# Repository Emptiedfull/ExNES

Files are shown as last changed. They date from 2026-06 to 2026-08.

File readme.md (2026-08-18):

# EXNES

A cycle accurate emulator for the Nintendo Entertainment System written in go, built for performance and compatiblity

The core offers a standalone package without any external dependencies and no timing, rendering or audio management preferences. Allowing for extensive compatiblity and ease of use. 

This repo ships with a sdl frontend for native applications and a web build that runs straight in the browser using web assembly. 

## Playing it 

### Web 

<p align="center">
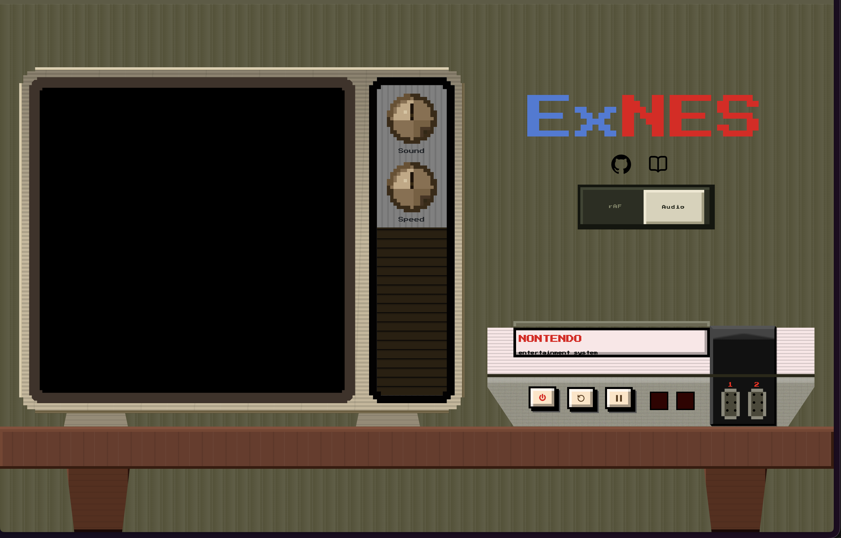
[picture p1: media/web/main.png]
  
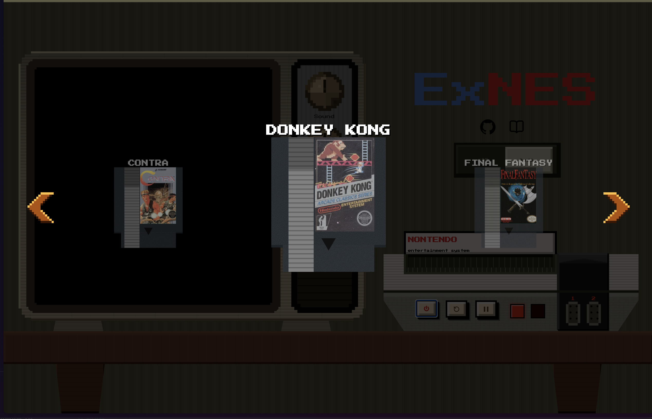
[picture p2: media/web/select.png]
   
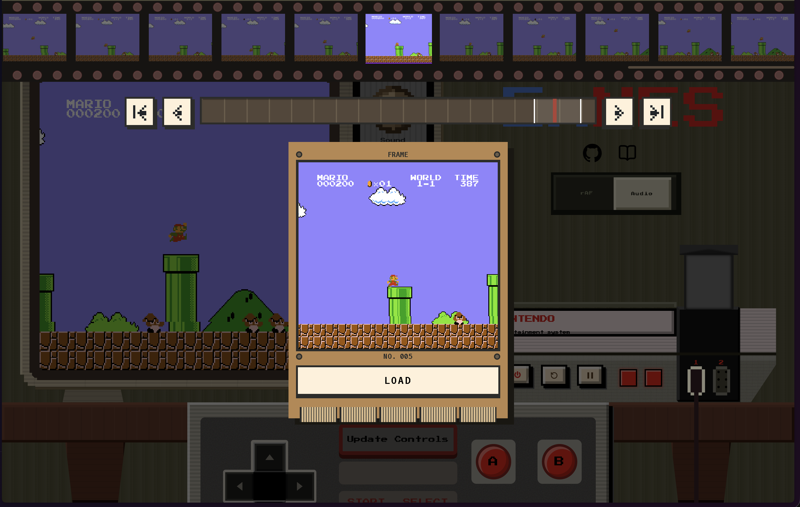
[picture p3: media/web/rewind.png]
    
</p>

The web build runs in any browser with support for shared memory array buffers (most major modern browsers). It is currently only playable on desktop browsers however. A curated set of roms is available built in however support for custom roms is not present. 

> **Hosted at:** https://exnes.a.shipwrights.dev/

## Native builds

<p align="center">
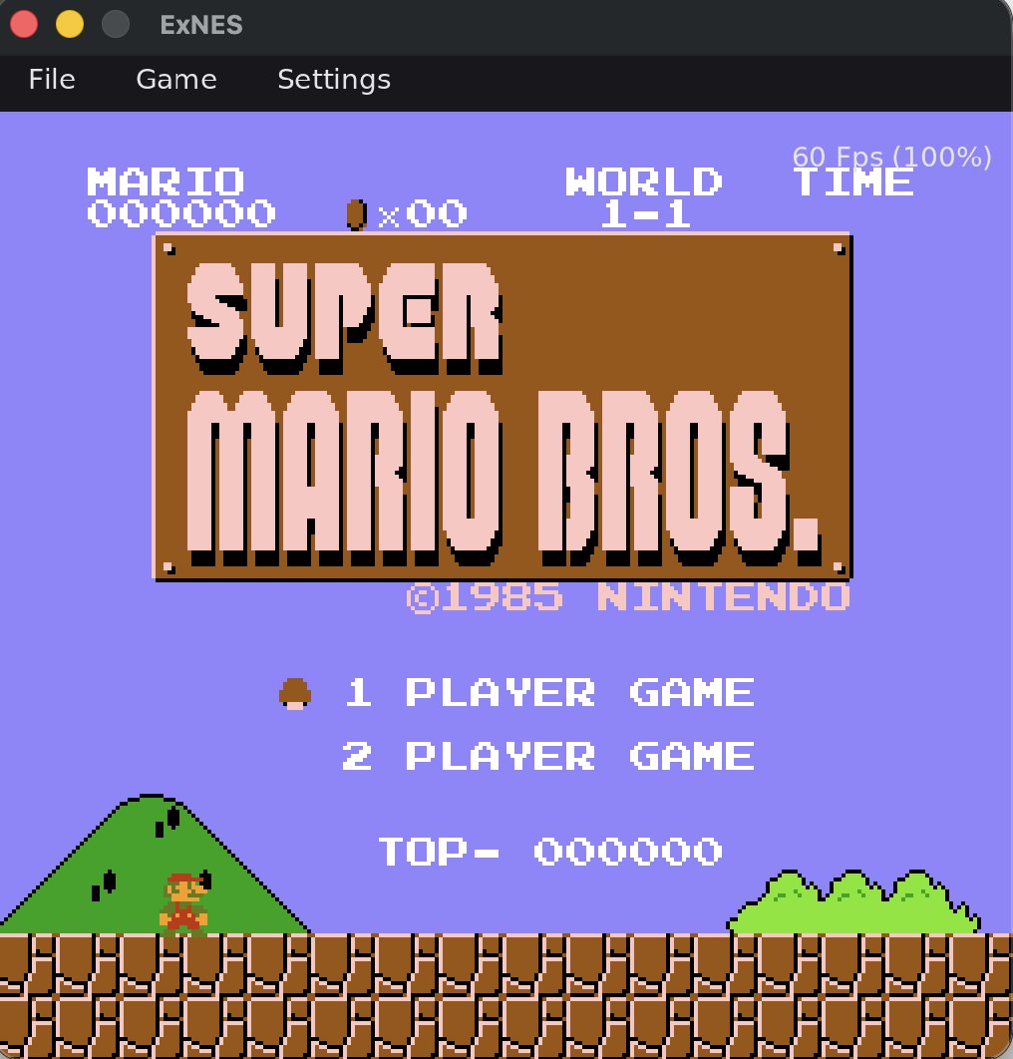
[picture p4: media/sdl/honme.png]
  
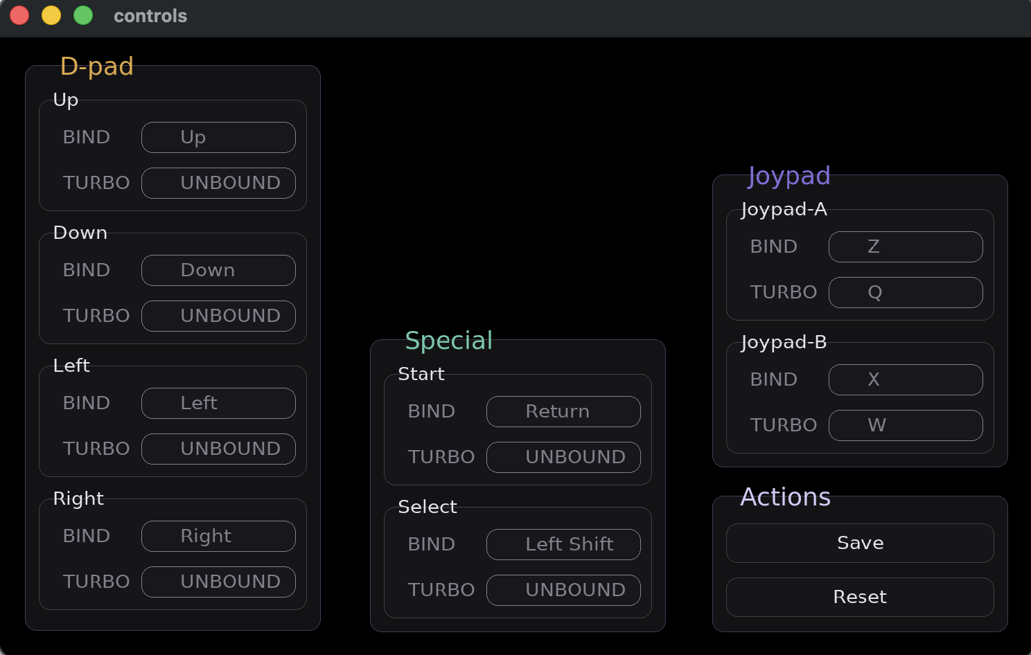
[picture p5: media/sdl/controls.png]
   
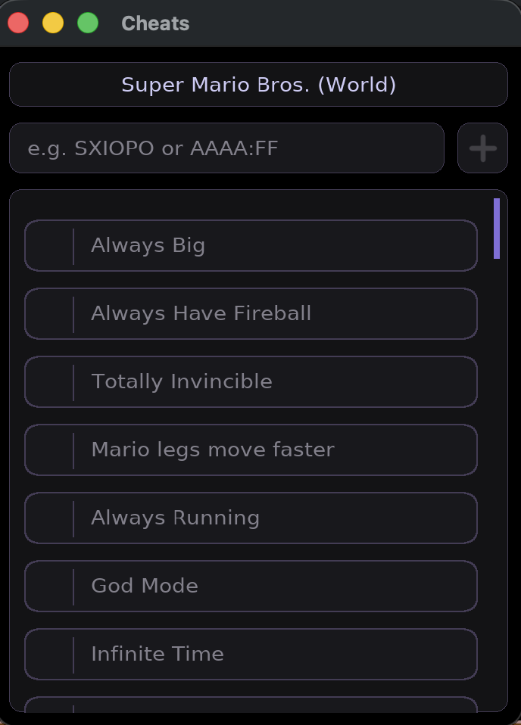
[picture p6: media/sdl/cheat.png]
    
</p>

Executables for Windows, Mac and Linux are available on the releases page. 

### Linux 

Release for linux happens through AppImages, there are no prerequisite dependencies or package manager involved. Stable AppImages can found in the releases page.

```
chmod +x ExNES-x86_64.AppImage
./ExNES-x86_64.AppImage
```
The appImage was built against `Debian 12(glic 2.36)` and hence will not work on older legacy systems, these including distributions like Ubuntu 22.04 and RHEL 8. On these systems build from source instead, a list of needed dependencies can be found in ` AppImage.sh `

### Mac 

MacOS version ships as a `.dmg` for both silicon based and intel based Macs. Due to the unsigned nature of the binary (it costs an arm and leg), the first run will require to explicity allow execution by going to `Settings > Privacy`.

> Dragging and Dropping files on the macOS edition will cause the emulator to crash, this is a known issue with no fix currently.

### Windows

Every release ships two options.

**Portable zip.** Download `ExNES-windows-x86_64.zip`, unpack it anywhere, and run
`exnes.exe`. Nothing is installed and nothing is written outside the app's own
config directory.

**Installer.** Download `ExNES-<version>-windows-x64-setup.exe` and run it. It
installs per-user by default, so Windows never prompts for admin rights, and it
adds Start Menu and optional desktop shortcuts.

Both are self-contained, SDL2 and everything else is bundled alongside the exe,
so there is no runtime to install and no package manager involved. 

The installer additionally registers `.nes` as a file type, which lets you launch
a ROM by double-clicking it, via right-click → Open With, or by dropping it onto
the ExNES icon.

> Neither download is code-signed yet, so SmartScreen will show a
> "Windows protected your PC" warning on first run. Click **More info** →
> **Run anyway**.
### Controls 

The default mappings are common across the native builds and are as follows: 

| NES button | Key | Turbo |
|---|---|---|
| D-pad | Arrow keys | — |
| A | `Z` | `Q` |
| B | `X` | `W` |
| Start | `Enter` | — |
| Select | `Left Shift` | — |

The default mappings can be changed by going to `Settings > Input`

Turbo buttons act like turbo buttons on the pro nes controllers and spam a given input while they are held.

### Whats included 

The desktop build comes with a sdl based application window with a lightweight custom made graphics and state handler. 

- Loading rom files from memory with recent files support 
- 10 Save states linked to ROM's hash 
- Battery backed ram support for included Mappers 
- Support for emulation control: Pause,Unpause,Reset,Power Cycle,etc
- Cheat suport in both memory and code format
- Hash based database support linked to cheats menu 
- Support for variable emualtion speed upto 3x
- Volume and fps control 
- Support for dynamic pallete changes
- Customizable controls 
- Turbo controls 
- File associations for os-dependent context menus 

All settings and battery backed ram saves are persistent and stored in: 

| Platform | Path |
|---|---|
| Linux | `~/.config/exnes` |
| macOS | `~/Library/Application Support/exnes` |
| Windows | `%AppData%\exnes` |

## Running it locally 

### Building from Source

Requires Go 1.24+, cgo, and SDL2 development headers.

> Installing depts:

```sh
# Debian / Ubuntu
sudo apt install libsdl2-dev libsdl2-ttf-dev libsdl2-image-dev libsdl2-gfx-dev
 
# macOS
brew install sdl2 sdl2_ttf sdl2_image sdl2_gfx
 
# MSYS2 (MINGW64 shell)
pacman -S mingw-w64-x86_64-toolchain mingw-w64-x86_64-SDL2 \
          mingw-w64-x86_64-SDL2_ttf mingw-w64-x86_64-SDL2_image \
          mingw-w64-x86_64-SDL2_gfx
```

> Building Binary 

```sh
go build -o exnes ./cmd/sdl
./exnes
```

### Using Release artifacts 

`.github/workflows/build.yml` builds all 4 dispatches on every github release, or on a manual action. 

For producing them locally: 

| Target | Command | Output |
|---|---|---|
| Linux  | `docker build -t exnes-build build/` then `build/AppImage.sh` | `dist/*.AppImage` |
| macOS `.dmg` | `bash build/macos.sh` | `dist/*.dmg` |
| Windows `.zip` | `bash build/windows.sh` (MSYS2 MINGW64) | `dist/*.zip` |
| Windows installer | `iscc /DAppVersion=1.0.0 build\installer.iss` | `dist/*-setup.exe` | 

### Running web build 

**Production:** The repository root has a `dockerfile` and `Caddyfile` that work as-is anywhere Docker runs:

```sh 
docker build -t exnes-web 
docker run -p 6000:80 exnes-web
```

The port can be manually changed in the `Caddyfile` but it currently lacks env variable support.

**Development:** `cmd/wasm/server` is a custom built development server specifically made for this project, by default it comes with automatic Wasm recompilation and bundling, brotli compression backed by an in memory cache, and generation support for files used by frontend. 

The default port is set to 8070

```sh
go run ./cmd/wasm/server
```

### Features

| Feature | Native build | Web build |
|---|---| --- |
| Speed Adjustment | ✅ |  ✅ | 
| Audio | ✅ |  ✅ | 
| Cheats | ✅ |  ❌ | 
| RAM memory |  ✅ | | 
| Rom Support | Custom |  Included | 

## Repository Map 

```
Core\           # Contains NES Core package 
Cmd\            # Entrypoints
    Sdl\            # Native frontend wtih sdl2
    Wasm\           # Web assembly build + Dev Server and bundler
    ssts\           # Test harness for single step tests
Build\          # Build scripts and artifacts
Media\          # Image gallery for readme
```

## Technical details 

### Emulator Core 

Present in ./CORE it contains all the neccesary functions and helpers responsible for emulating the NES Console.

It includes a cycle accurate 6502 Rioch 2A03 cpu with full opcode coverage including all illegal and unstable opcodes. These are tested against [SingleStepTests](https://github.com/SingleStepTests/65x02) `nes6502/v1`. Along with cycle accuracy for opcodes, it also contains cycle accurate state machines for interrupts.

NOTE: The cooked branch includes a sub cycle accurate RDY pin behaviour but it is currently unstable and cant be used freely without risk of crash. 

It also includes a dot accurate PPU working based on the og nes fetcher model stimulating all dummy reads and writes present in the dot, this is in conjuction with a dynamically swappable pallete engine with supports both single and full palettes.

The Apu is a standard 5 channel audio engine based on the global clock. 

The core has been built to maximize the accuracy while refraining from entering subcycle (or more) accurate behaviour to mitigate performance issues. This means it accurately stimulates a large amount of quirks and edge cases present in the orignal console. As per the latest release the emulator core scores 86 in the AccuracyCoin which puts it ahead of many commercial and nintendo made emulators for the NES.

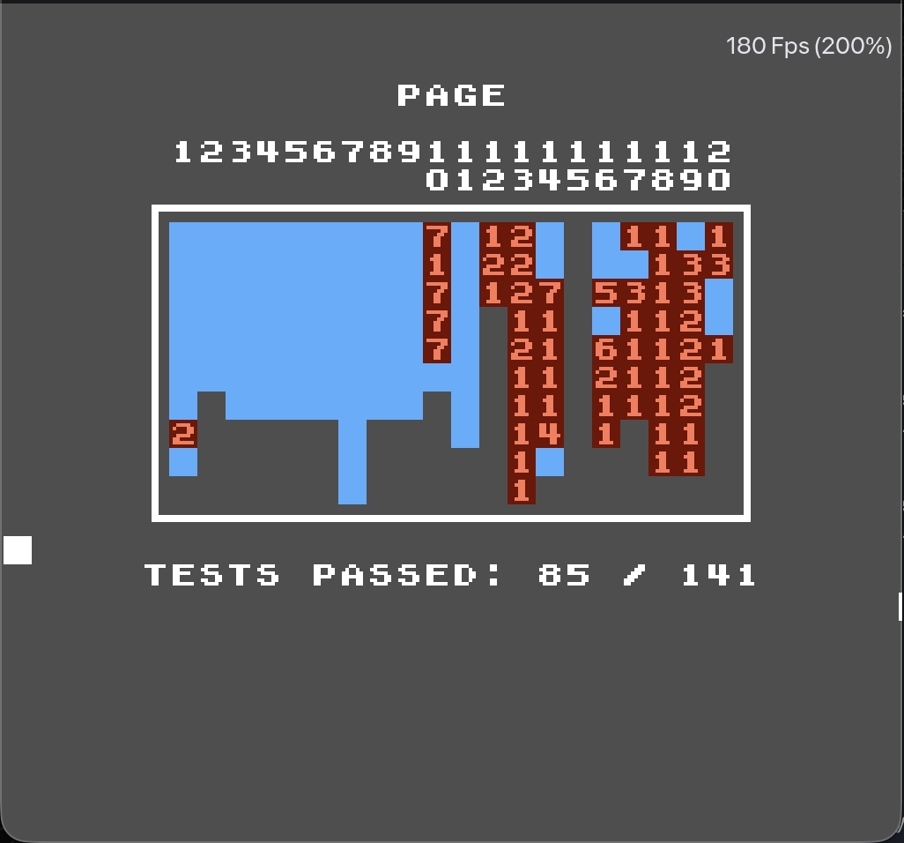
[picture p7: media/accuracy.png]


One thing to note is that the Core does not expose any timing mechanism on its own nor does it enforce any, consumption of the core needs to come with its own timing mechanism, it is recommend to either sync using runFrame at around 60fps or use the audio sample starvation for frame perfect emulation.

The core also included a cheat engine which supports game genie codes along with support for raw memory patches in the format of addr:val.

Also bundled in is a headerless No-Intro dataset for indentification of games, this information is used for generating accurate saves and it also connects with the cheat engine to provide all known cheats for a game through a easily querable function.

The documentation for how to use the core is scarce and not very intuituive, hence the best way to utilize it right now is looking at cmd/wasm and cmd/sdl for sample code. 

### Web build 

The web build serves the emulator core using web assembly, due to the single threaded nature of javascript runtime in browsers multiple threads with atomic messages run in parralel. 

These are the following:

1) Go web worker: Residing in emuWorker.js this thread owns the go runtime and runs the emulator itself, it spends most of time blocking on frame signals and can only be communicated using shared Array buffers.

2) Audio worklet: runs the audio worklet process, it is also responsible for driving the emulator thread when in audio synced mode. 

3) Main thread: It handles all the other processes including handling button inputs, cross thread communication and animations.

### Native build

The native build runs cross platform by utilizing the sdl library, it includes no dependencies apart from sdl including a layout engine. This means that every window contains its own discrete layout engine and state manager, a lot of this values are hardcoded for ease of development and thus extensions should be carefully made.

It is technically supposed to work on every platform due to the cross platform nature of golang and sdl, but its only been tested on macOs. Please report any issues on other platforms.

## Contributions 

Issues and pull requests are welcome. Platform reports are especially useful, the desktop build is tested mainly on macOS, so Linux and Windows regressions tend to be found by users rather than by CI.

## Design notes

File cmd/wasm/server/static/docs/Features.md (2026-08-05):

# Features

This page is a comphrensive list of all available features (hopefully)

## Console Controls 

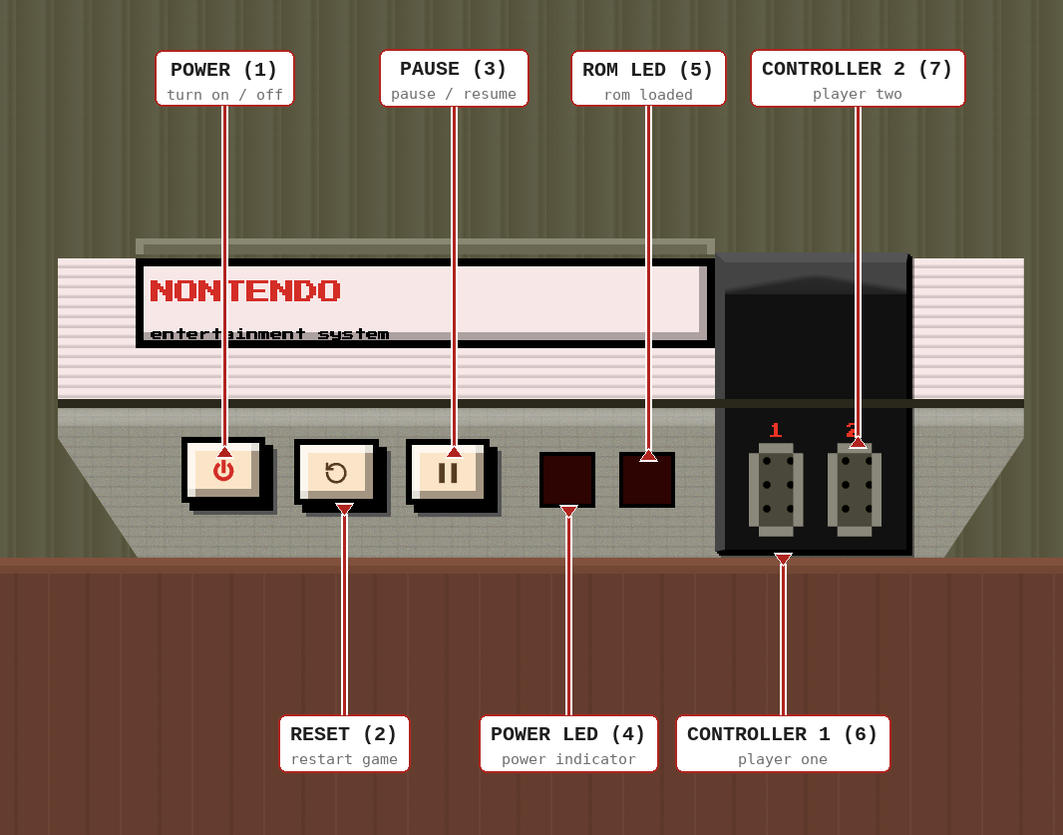
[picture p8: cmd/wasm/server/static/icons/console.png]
hehe


### Power button (1)

Controls the physical state of being **powered**. It also is the start of the console. Turning it on and off stimulates a **power cycle** like on the orignal NES.

## Reset (2)

Works like the **reset** button on the physical NES. May cause data corruption in some games (this is not a glitch, this is a artifact of accurate emulation)

## Play/Pause (3)

Can be used to control the state of emulation. The pausing action is not instant and may cause **5-10 frames** of lag.

### Power led and ROM Led (4 and 5)

This represent the state of the console at a given point. Note any flickering effects are purely **cosmetic** and do not affect 
usage.

If your rom has been loaded but the power led remains blank, use the **power button** to turn on the console.

### Controller ports (6 and 7)

Uh my bad they aren't really implemented yet but they would allow you to use external control devices and connect and disconnect input sources. Have a happy cat on me instead. 

### Catridge slot (8)

Press on the **slot** to open up the rom selection menu. Using it mid game can be used to hotswap games which can be used for some exploits in particular games, it can also however cause data corruption. Restart the tab to fix this.

***

## Television controls 

### Speed dial(1)

It can be used to control the **emulation speed** to slow or speed it up, by defualt the increment are in orders of **50%**. Only works in audio clocked mode.

### Volume dial(2)

Pretty obvious, controls the **audio volume**. Can be used to **mute** the program. Only works in audio clocking mode.

### Tv Screen

Clicking on the screen changes the display mode to **fullscreen**, the scaling is based on the browser auto scaling so pixel ratio might be distorted.

***

## Miscellanous 

### Timing control

Probably the most drastic control option you have the liberty to change. Check out [here](./docs/Timing.md) for more info

### Updating controls 

The **on screen controller** can be used to change up the controls, simply press the button and then rebind it with any keyboard key (or hopefully external controller but no promises). The onscreen controller can also be used to actually control the emulator btw!

### Rewind

You found the **easter egg**!!!! Press the R key on the keyboard to open up the **rewind** overlay, you can then use the timeline to scrub into a past frame from a collection of the **last 4 seconds of frames**. The frame can then be loaded into for rewinding, enjoy cheating you lil bitch.

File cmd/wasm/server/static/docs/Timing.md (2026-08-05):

# Timing Modes

ExNES supports a two different ways of timing the emulator clock. This should not concern most people but it can be the source of your problem. 

## Which mode to use? 

The default mode at start up is Audio clocked, this is because it has the most extensive feature support. However you might find that using audio clocked makes the game jittery try to switch to rAF Clocked.

## How to switch modes? 

Gng, its the most akward button on the screen, just use the slider beneath the hero text.

## Comparison 

| | Audio Clocked | rAF Clocked |
|---|---|---|
| Compatiblity | Medium | High |
| Frame rate | Frame perfect |  ~60 fps |
|Audio | Supported | Not Supported |

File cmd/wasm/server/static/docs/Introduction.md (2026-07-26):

# EXNES

Welcome to **ExNES**, a Nintendo Entertainment System emulator running using WASM. Use this page for getting started.

## Starting

The console starts off. To boot it up:

1. Press the **power button** (the ⏻ button on the console deck). 
2. Use the **navigation arrows**
  to browse through the available games.
3. Click the **selected cartridge** to slot it in.

## Controls

ExNES maps the NES controller to your keyboard by default. 

| Button | Keyboard Key |
| --- | --- |
| A | `Z` |
| B | `X` |
| Select | `Left Shift` |
| Start | `Enter` |
|  Up | `Arrow Up` |
|  Down | `Arrow Down` |
| Left | `Arrow Left` |
| Right. | `Arrow Right`|

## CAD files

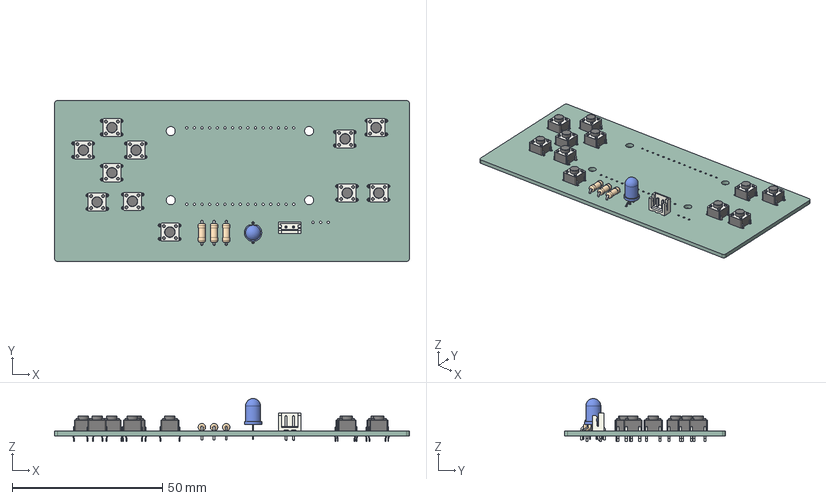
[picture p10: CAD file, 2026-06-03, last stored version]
controller_kicad/.step
118.0 x 53.5 x 14.3 mm
SW_PUSH_6mm_h5mm x 11
R_Axial_DIN0207_L63mm_D25mm_P762mm_Horizontal x 3
JST_B2B_EH_A
LED_D5.0mm-4_RGB_Wide_Pins
KiCad_PCB

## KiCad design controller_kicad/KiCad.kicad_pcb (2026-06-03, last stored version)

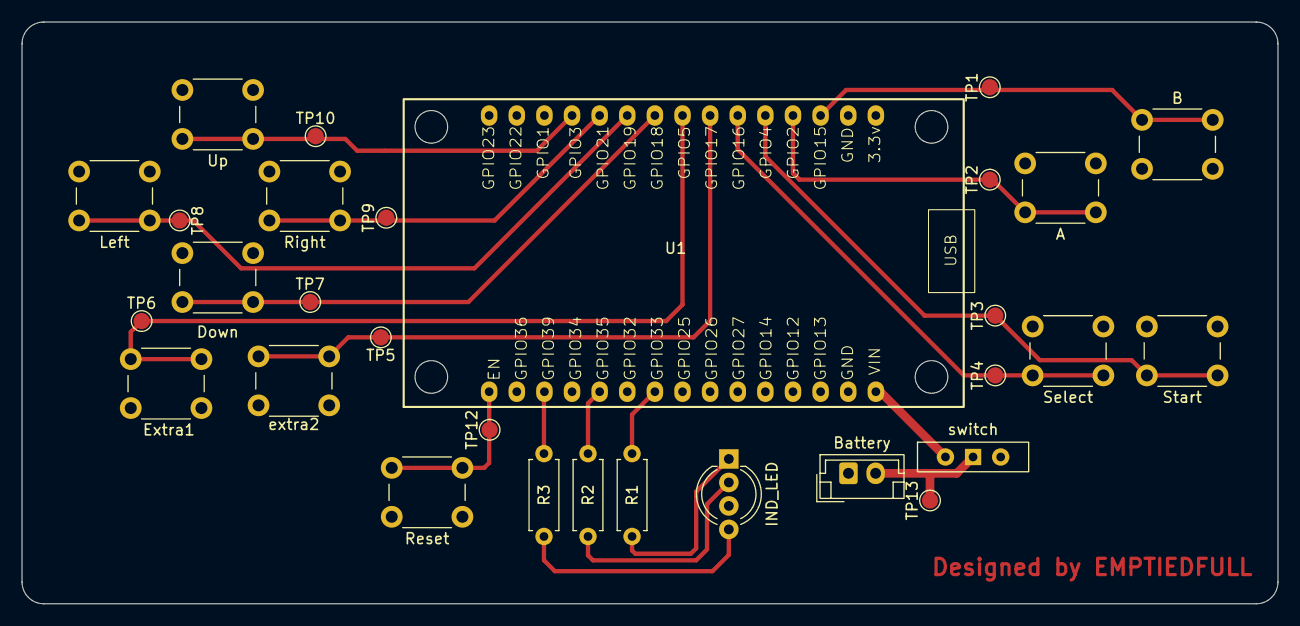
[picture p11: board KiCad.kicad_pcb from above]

Board: 2 copper layers, 115.5 x 53.5 mm, 30 parts (0 on the bottom side), 20 nets.

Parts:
A: ButtonA; SW_PUSH_6mm_H5mm
B: ButtonB; SW_PUSH_6mm_H5mm
Battery: GRND; JST_EH_B2B-EH-A_1x02_P2.50mm_Vertical
Down: ButtonStart; SW_PUSH_6mm_H5mm
Extra1: Extra1; SW_PUSH_6mm_H5mm
IND_LED: LED_BGKR; LED_D5.0mm-4_RGB_Wide_Pins
Left: ButtonSelect; SW_PUSH_6mm_H5mm
R1, R2, R3: R; R_Axial_DIN0207_L6.3mm_D2.5mm_P7.62mm_Horizontal
Reset: Reset; SW_PUSH_6mm_H5mm
Right: Extra1; SW_PUSH_6mm_H5mm
Select: ButtonSelect; SW_PUSH_6mm_H5mm
Start: ButtonStart; SW_PUSH_6mm_H5mm
TP1, TP2, TP3, TP4, TP5, TP6, TP7, TP8, TP9, TP10, TP12, TP13: TestPoint; TestPoint_Pad_D1.5mm
U1: ESP32_30pin
Up: Extra2; SW_PUSH_6mm_H5mm
extra2: Extra2; SW_PUSH_6mm_H5mm
switch: SW_SPDT; SW_Slide-03_Wuerth-WS-SLTV_10x2.5x6.4_P2.54mm

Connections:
unnamed: A.2, B.2, Battery.1, Down.2, Extra1.2, IND_LED.3 (K), Left.2, Reset.1, Right.2, Select.2, Start.2, U1.2 (GND), Up.2, extra2.2
unnamed: Battery.2, TP13.1 (1_1), switch.1 (A)
unnamed: IND_LED.1 (BA), R1.2
unnamed: IND_LED.2 (GA), R2.2
unnamed: IND_LED.4 (RA), R3.2
unnamed: U1.1 (VIN), switch.2 (B)
unnamed: Reset.2, TP12.1 (1_1), U1.15 (EN)
unnamed: A.1, TP2.1 (1_1), U1.19 (GPIO2)
unnamed: TP10.1 (1_1), U1.27 (GPIO3), Up.1
unnamed: Start.1, TP3.1 (1_1), U1.20 (GPIO4)
unnamed: Extra1.1, TP6.1 (1_1), U1.23 (GPIO5)
unnamed: B.1, TP1.1 (1_1), U1.18 (GPIO15)
unnamed: Select.1, TP4.1 (1_1), U1.21 (GPIO16)
unnamed: TP5.1 (1_1), U1.22 (GPIO17), extra2.1
unnamed: Down.1, TP7.1 (1_1), U1.24 (GPIO18)
unnamed: Left.1, TP8.1 (1_1), U1.25 (GPIO19)
unnamed: Right.1, TP9.1 (1_1), U1.26 (GPIO21)
unnamed: R1.1, U1.9 (GPIO33)
unnamed: R2.1, U1.11 (GPIO35)
unnamed: R3.1, U1.13 (GPIO39)

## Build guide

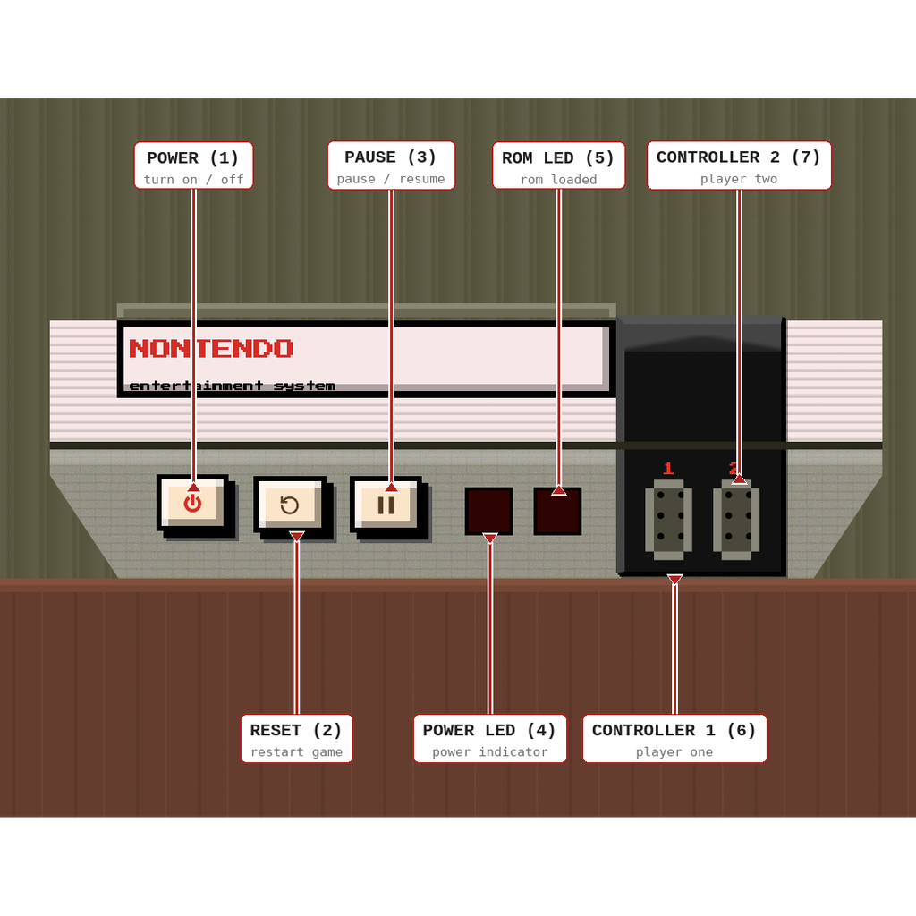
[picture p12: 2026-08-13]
build/exnes-1024.png

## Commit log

2026-06-03 controller-pcb added
    [.step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]
2026-06-03 Update README with PCB design and images
    Added images and updated PCB design information in README.
2026-06-03 added bom
    [bom.csv]
2026-06-04 socket support
2026-06-05 control n socket barely working
2026-06-11 better frame handling(like way better went from +- 10000 variation to +-2 variation of cycles
2026-06-12 switching to dot based rendering
2026-06-12 ppu switch complete-bugs remaining
2026-06-14 project restructing n pruning extra files
    [.step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]
2026-06-14 switched to tinygo compilation
2026-06-16 rom slottin
2026-06-18 apu prototype done
2026-06-19 complete audio driven+switched from oto to malgo
2026-06-20 switched to aduoi worklet
2026-06-21 switched to web worker for wasm
2026-06-26 added modal links with animations + added pause play and rom hotswap support is back(still gotta add buttons but yeh
2026-06-28 switched to a new icon library and added key animations for them
2026-06-29 changed pallete access to be branchless and hooked up pause button, also removed some logging calls
2026-07-01 new styles and animations for the reel track
2026-07-03 save cart and slot designs
2026-07-07 linked in the pause n play buttons and reverted some chaching changes
2026-07-07 added icon support and linked the reset button
2026-07-07 linked in the speed buttons and added a new system for handling custom speed modifiers
2026-07-08 introduced multiple window contexts and switched main loop
2026-07-08 switching focus to core so commmiting as checkpoint
2026-07-12 added the other 2 button grousp
2026-07-13 hooked up the turbo buttons
2026-07-14 linked the action buttons and fixed texture clean up glitches
2026-07-18 battery backed ram
2026-07-19 fFixed battery backed ram
2026-07-22 patchwork commit for uploading case change
2026-07-23 ui start for the timing mode switch slider
2026-08-09 synchronized all interrupts and made a common state machine for them
2026-08-09 minor bug fixes, patched up dmc and fixed interrupt glitches
2026-08-10 switched to in memory icons
2026-08-12 fixed socket server enough to pass compile
2026-08-12 tmp commit for case change
2026-08-12 fix mime type case issue
2026-08-18 removed legacy socket server
